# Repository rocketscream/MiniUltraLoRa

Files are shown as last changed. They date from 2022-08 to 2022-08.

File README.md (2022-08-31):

# Mini Ultra LoRa
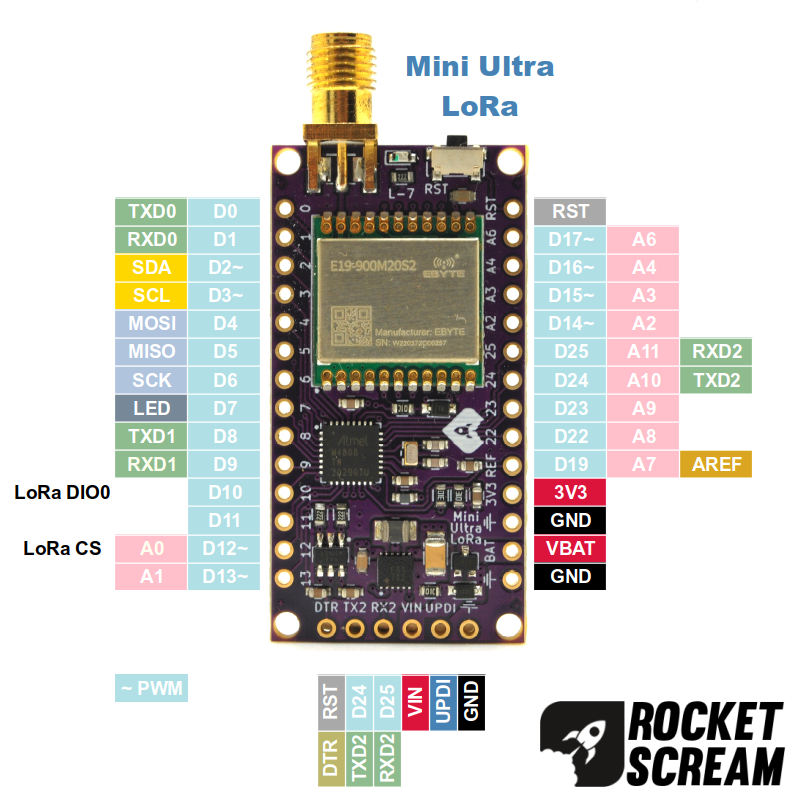
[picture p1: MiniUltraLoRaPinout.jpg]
Mini Ultra LoRa

Mini Ultra LoRa is an Arduino compatible ATmega4808 board that is suitable for ultra low power wireless applications. During deep sleep mode, the board consumes only 5 uA (with the on-board radio module in sleep mode) when powered by a 3.6 V source. The board comes equipped with a 2Kb I2C serial EEPROM with pre-programmed EUI-64™ MAC ID 24AA025E64T chip to be used as DEVEUI in a LoRaWAN network and E19-900M20S2 LoRa radio module. Option to use various battery type, cell combination and chemistry such as 2xAA or 3xAA (alkaline, NiMH), CR123A, LiFeFO4, and Li-Ion/Pol. No charger IC is included on-board.

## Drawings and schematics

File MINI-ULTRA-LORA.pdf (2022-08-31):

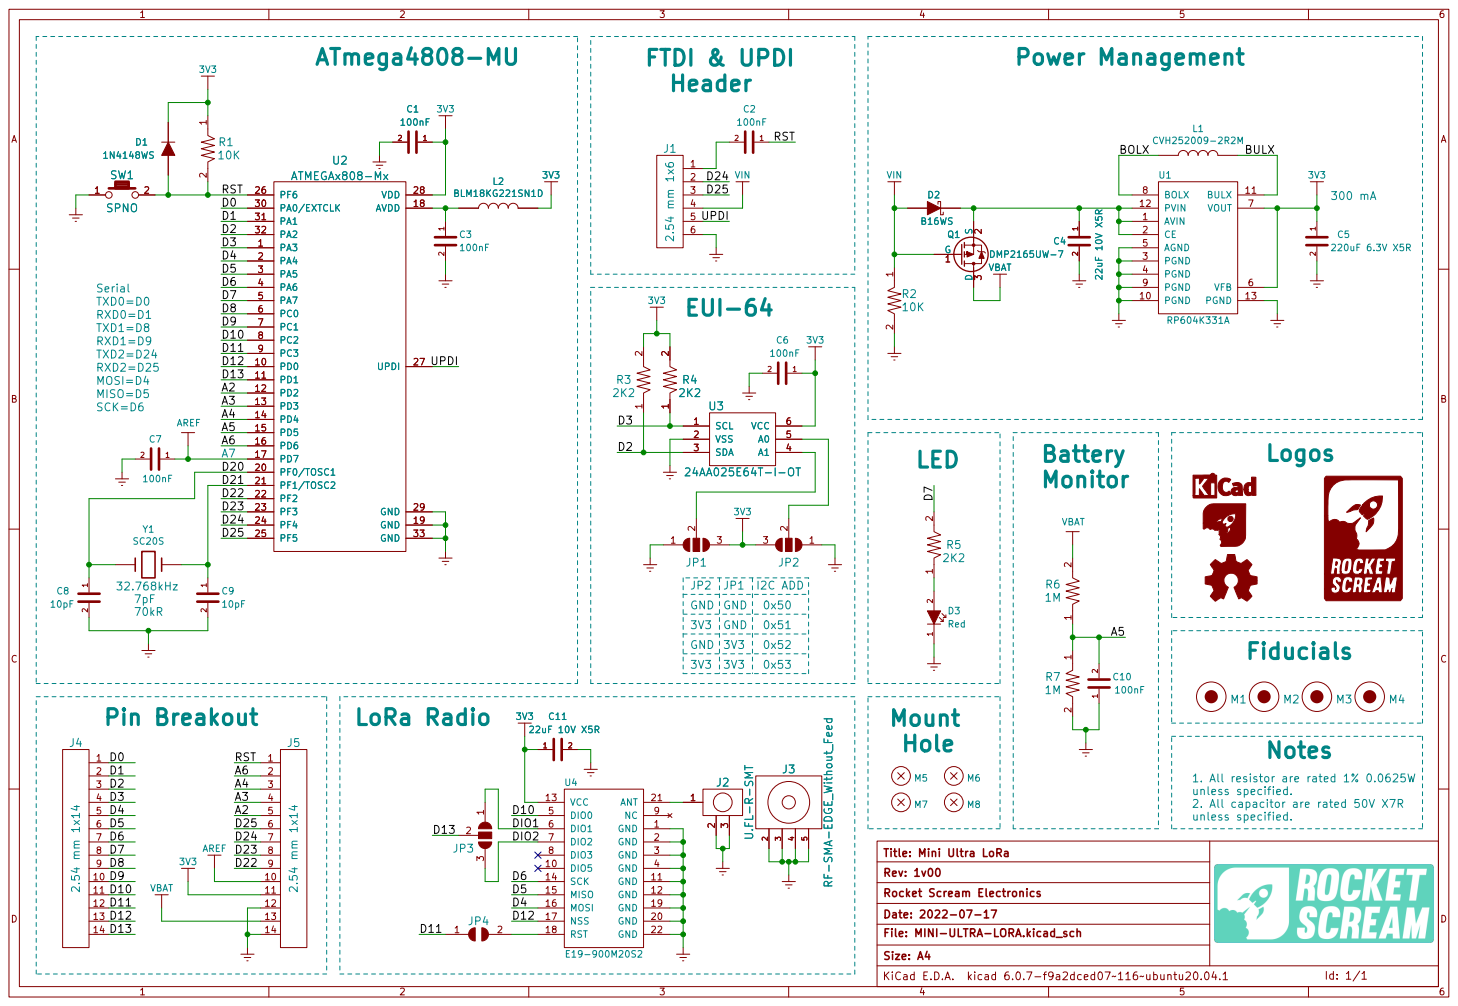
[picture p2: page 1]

JP2 | | I2C ADD
GND
3V3 | GND | 0x51

3 J2 GND U.FL-R-SMT 1 DIO5 10 GND 11 GND 12 VCC 13 SCK 14 MISO 15 MOSI 16 NSS 17 RST 18 GND 19 GND 2 GND 20 ANT 21 GND 22 GND 3 GND 4 DIO0 5 DIO1 6 DIO2 7 DIO3 8 NC 9 U4E19-900M20S2

1. All resistor are rated 1% 0.0625W unless specified.

2. All capacitor are rated 50V X7R
unless specified.

Id: 1/1 Title: Mini Ultra LoRa File: MINI-ULTRA-LORA.kicad_sch Rocket Scream Electronics
D Date: 2022-07-17 KiCad E.D.A. kicad 6.0.7-f9a2dced07~116~ubuntu20.04.1 Rev: 1v00 Size: A4

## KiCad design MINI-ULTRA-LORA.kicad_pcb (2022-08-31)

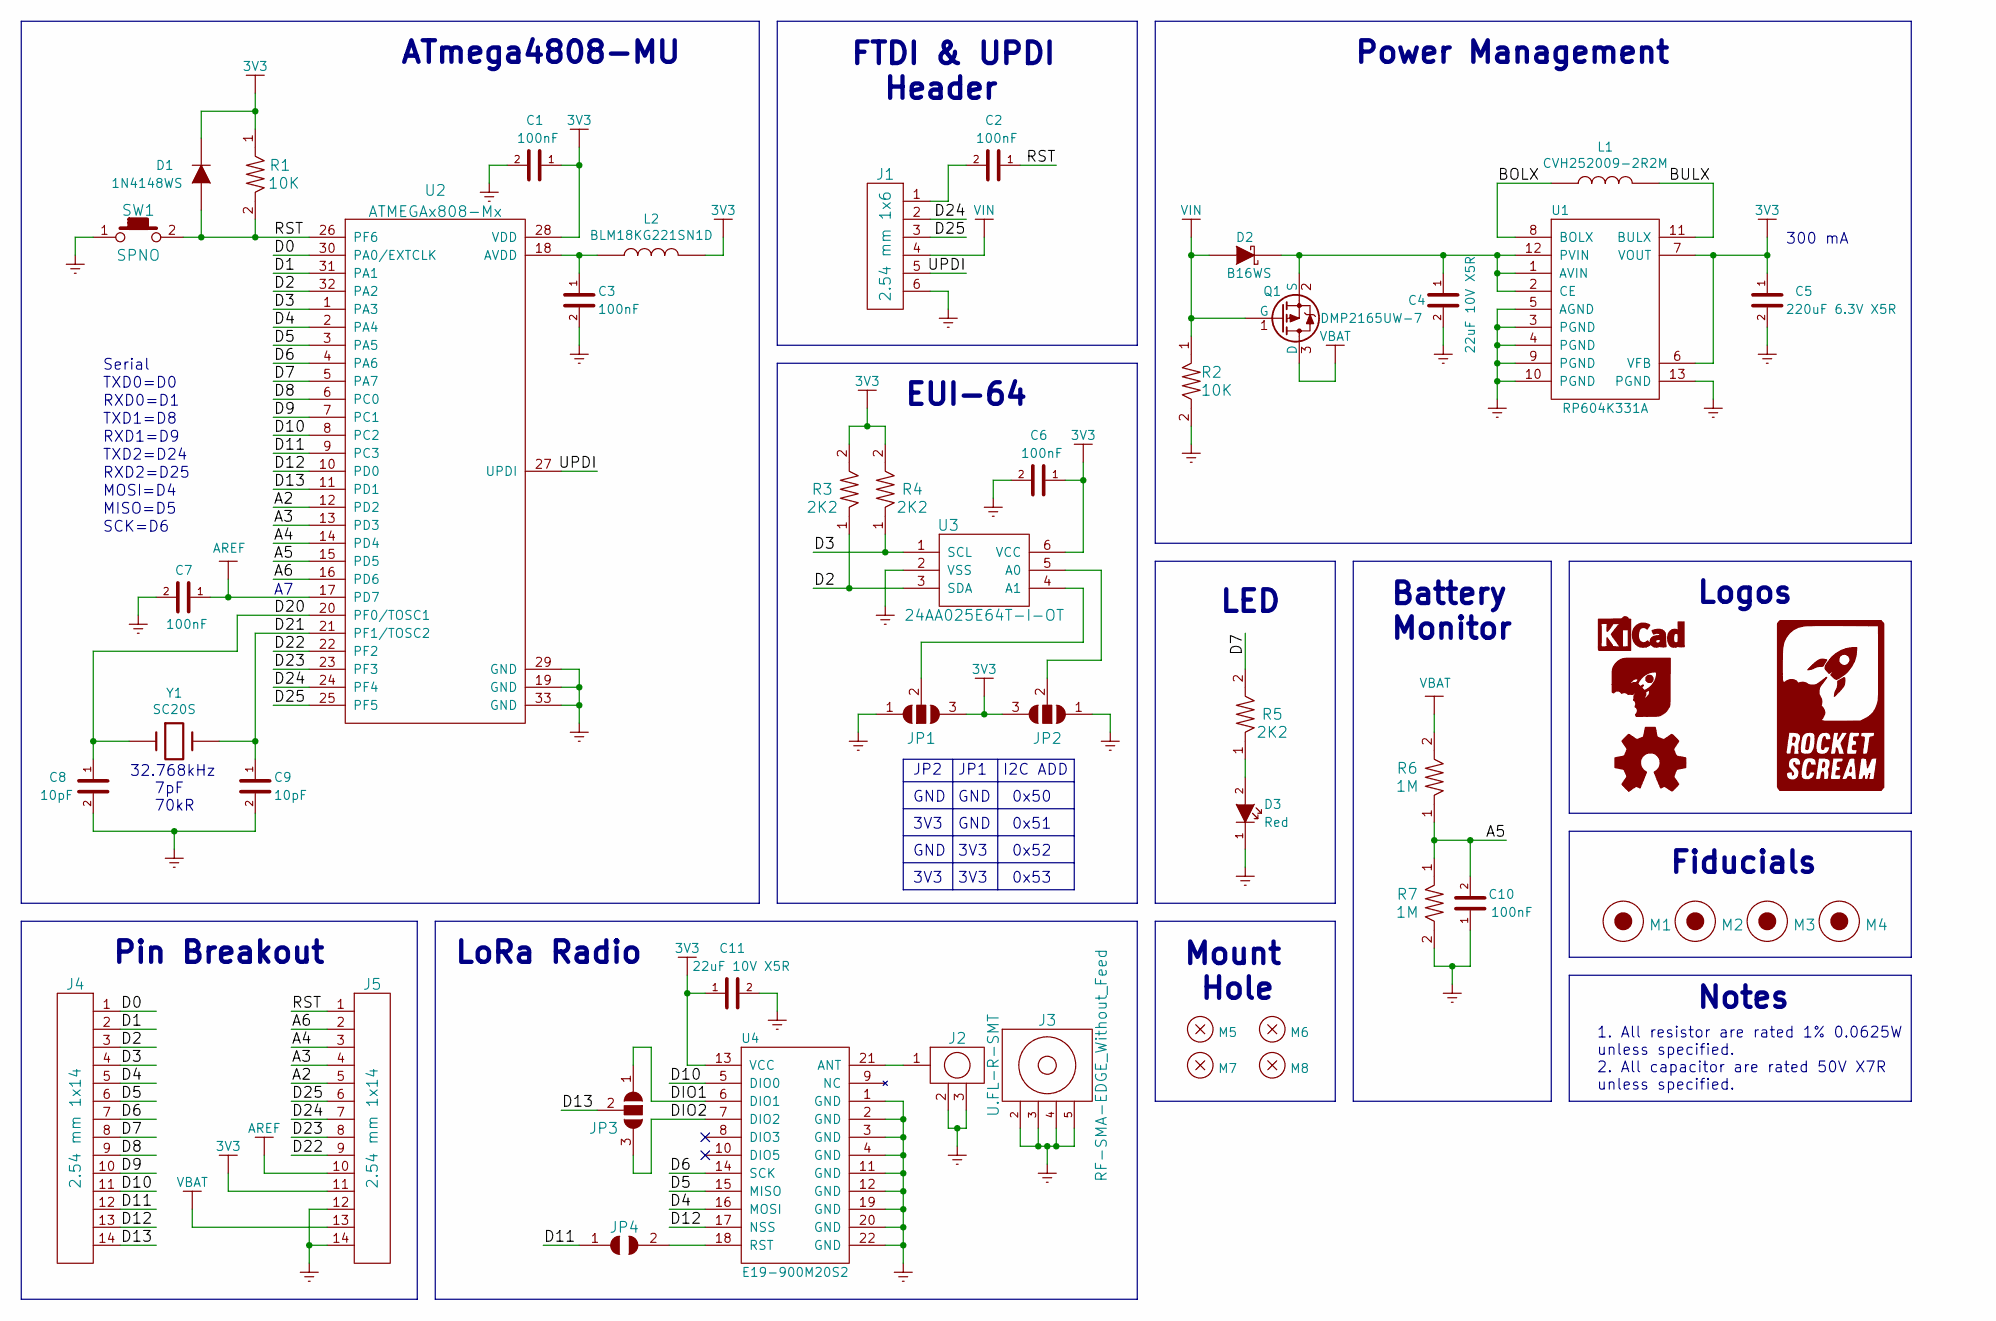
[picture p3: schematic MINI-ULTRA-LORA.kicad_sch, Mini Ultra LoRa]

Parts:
C1, C2, C3, C6, C7, C10: 100nF; C_0603
C4, C11: 22uF 10V X5R; C_0603
C5: 220uF 6.3V X5R; C_1206
C8, C9: 10pF; C_0603
D1: 1N4148WS; SOD-323
D2: B16WS; SOD-323
D3: Red; LED_0603
J1: 2.54 mm 1x6; HDR_1x6_Pitch2.54mm
J2: U.FL-R-SMT
J3: RF-SMA-EDGE_Without_Feed
J4, J5: 2.54 mm 1x14; HDR_1x14_Pitch2.54mm
JP1, JP2, JP3: JUMPER-2-WAY; JUMPER-2-WAY-SMD
JP4: JUMPER-1-WAY; JUMPER-1-WAY-SMD
L1: CVH252009-2R2M; I_2520
L2: BLM18KG221SN1D; I_0603
LOGO1: LOGO-KICAD; LOGO-KICAD_XXXSmall
LOGO2: LOGO-ROCKET-SCREAM-WITHOUT-TEXT; LOGO-ROCKET-SCREAM_Without_Text_XXXXSmall
LOGO3: LOGO-ROCKET-SCREAM-VERTICAL; LOGO-ROCKET-SCREAM_Vertical_XSmall
LOGO4: LOGO-OSHW; LOGO-OSHW_XXSmall
M1, M2, M3, M4: FIDUCIAL; FIDUCIAL-0.5MM_CROSS
M5, M6, M7, M8: MOUNT_HOLE; HOLE_NPTH_2.2MM
Q1: DMP2165UW-7; SOT-323
R1, R2: 10K; R_0603
R3, R4, R5: 2K2; R_0603
R6, R7: 1M; R_0603
SW1: SPNO; TS-1086E-12
U1: RP604K331A; DFN-12
U2: ATMEGAx808-Mx; QFN-32_5x5mm_Pitch0.5mm
U3: 24AA025E64T-I-OT; SOT-23-6
U4: E19-900M20S2
Y1: SC20S; SC-20S

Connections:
3V3: C1.1, C5.1, C6.1, C11.1, D1.1 (K), J5.11, JP1.3, JP2.3, L2.2, R1.1, R3.2, R4.2, U1.6 (VFB), U1.7 (VOUT), U2.28 (VDD), U3.6 (VCC), U4.13 (VCC)
/A2: J5.5, U2.12 (PD2)
/A3: J5.4, U2.13 (PD3)
/A4: J5.3, U2.14 (PD4)
/A5: C10.2, R6.1, R7.1, U2.15 (PD5)
/A6: J5.2, U2.16 (PD6)
/BOLX: L1.1, U1.8 (BOLX)
/BULX: L1.2, U1.11 (BULX)
/D0: J4.1, U2.30 (PA0/EXTCLK)
/D1: J4.2, U2.31 (PA1)
/D2: J4.3, R3.1, U2.32 (PA2), U3.3 (SDA)
/D3: J4.4, R4.1, U2.1 (PA3), U3.1 (SCL)
/D4: J4.5, U2.2 (PA4), U4.16 (MOSI)
/D5: J4.6, U2.3 (PA5), U4.15 (MISO)
/D6: J4.7, U2.4 (PA6), U4.14 (SCK)
/D7: J4.8, R5.2, U2.5 (PA7)
/D8: J4.9, U2.6 (PC0)
/D9: J4.10, U2.7 (PC1)
/D10: J4.11, U2.8 (PC2), U4.5 (DIO0)
/D11: J4.12, JP4.1, U2.9 (PC3)
/D12: J4.13, U2.10 (PD0), U4.17 (NSS)
/D13: J4.14, JP3.2, U2.11 (PD1)
/D20: C8.1, U2.20 (PF0/TOSC1), Y1.1
/D21: C9.1, U2.21 (PF1/TOSC2), Y1.2
/D22: J5.9, U2.22 (PF2)
/D23: J5.8, U2.23 (PF3)
/D24: J1.2, J5.7, U2.24 (PF4)
/D25: J1.3, J5.6, U2.25 (PF5)
/DIO1: JP3.1, U4.6 (DIO1)
/DIO2: JP3.3, U4.7 (DIO2)
/RST: C2.1, D1.2 (A), J5.1, R1.2, SW1.2, U2.26 (PF6)
/UPDI: J1.5, U2.27 (UPDI)
AREF: C7.1, J5.10, U2.17 (PD7)
GND: C1.2, C3.2, C4.2, C5.2, C6.2, C7.2, C8.2, C9.2, C10.1, C11.2, D3.1 (K), J1.6, J2.2, J2.3, J3.2, J3.3, J3.4, J3.5, J5.12, J5.14, JP1.1, JP2.1, R2.2, R7.2, SW1.1, U1.3 (PGND), U1.4 (PGND), U1.5 (AGND), U1.9 (PGND), U1.10 (PGND), U1.13 (PGND), U2.19 (GND), U2.29 (GND), U2.33 (GND), U3.2 (VSS), U4.1 (GND), U4.2 (GND), U4.3 (GND), U4.4 (GND), U4.11 (GND), U4.12 (GND), U4.19 (GND), U4.20 (GND), U4.22 (GND)
unnamed: C2.2, J1.1
unnamed: C3.1, L2.1, U2.18 (AVDD)
unnamed: C4.1, D2.1 (K), Q1.2 (S), U1.1 (AVIN), U1.2 (CE), U1.12 (PVIN)
unnamed: D3.2 (A), R5.1
unnamed: J2.1, U4.21 (ANT)
unnamed: JP1.2, U3.4 (A1)
unnamed: JP2.2, U3.5 (A0)
unnamed: JP4.2, U4.18 (RST)
VBAT: J5.13, Q1.3 (D), R6.2
VIN: D2.2 (A), J1.4, Q1.1 (G), R2.1

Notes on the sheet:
Notes
Logos
3V3
FTDI & UPDI Header
GND
0x52
Serial
TXD0=D0
MOSI=D4
300 mA
TXD2=D24
RXD0=D1
EUI-64
1. All resistor are rated 1% 0.0625W unless specified. 2. All capacitor are rated 50V X7R unless specified.
ATmega4808-MU
MISO=D5
Power Management
JP2
LED
Mount Hole
SCK=D6
Battery Monitor
Pin Breakout
RXD1=D9
32.768kHz 7pF 70kR
Fiducials
I2C ADD
RXD2=D25
LoRa Radio
0x53
0x51
0x50
JP1
TXD1=D8

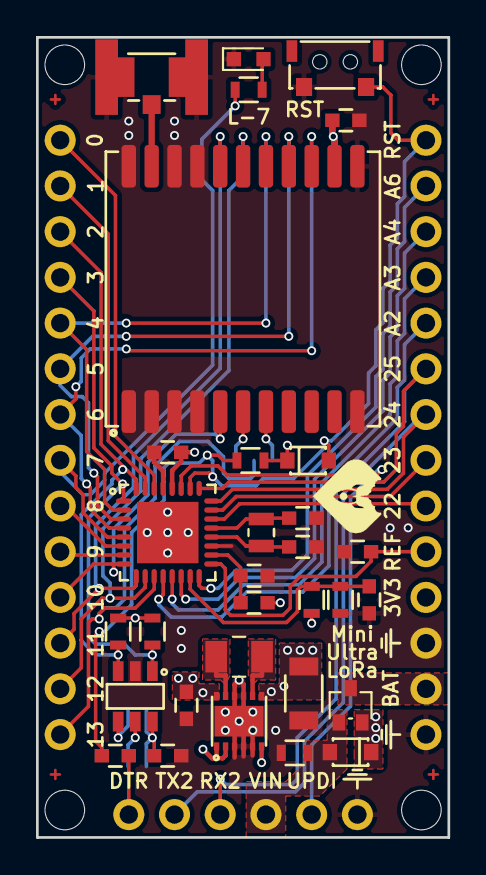
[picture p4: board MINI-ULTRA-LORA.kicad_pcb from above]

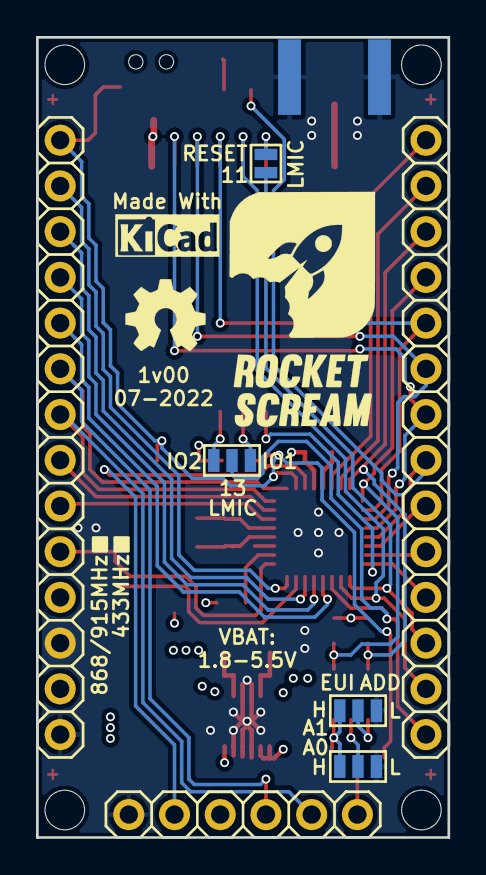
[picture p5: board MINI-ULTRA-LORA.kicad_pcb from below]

Board: 4 copper layers, 22.9 x 44.4 mm, 51 parts (10 on the bottom side), 44 nets.

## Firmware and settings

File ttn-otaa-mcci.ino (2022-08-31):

/*******************************************************************************
   Copyright (c) 2015 Thomas Telkamp and Matthijs Kooijman
   Copyright (c) 2018 Terry Moore, MCCI

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
   This example sends a valid LoRaWAN packet with payload "Hello,
   world!", using frequency and encryption settings matching those of
   the The Things Network.

   This uses OTAA (Over-the-air activation), where where a DevEUI and
   application key is configured, which are used in an over-the-air
   activation procedure where a DevAddr and session keys are
   assigned/generated for use with all further communication.

   Note: LoRaWAN per sub-band duty-cycle limitation is enforced (1% in
   g1, 0.1% in g2), but not the TTN fair usage policy (which is probably
   violated by this sketch when left running for longer)!

   To use this sketch, first register your application and device with
   the things network, to set or generate an AppEUI, DevEUI and AppKey.
   Multiple devices can use the same AppEUI, but each device has its own
   DevEUI and AppKey.

   Do not forget to define the radio type correctly in
   arduino-lmic/project_config/lmic_project_config.h or from your BOARDS.txt.

 *******************************************************************************/

#include <lmic.h>
#include <hal/hal.h>
#include <SPI.h>
#include <Wire.h>
#include <RocketScream_RTCAVRZero.h>
#include <RocketScream_LowPowerAVRZero.h>
#define EUI64_CHIP_ADDRESS 0x50
#define EUI64_MAC_ADDRESS 0xF8
#define EUI64_MAC_LENGTH 0x08
#define MAX_DATA_SIZE 2

const uint8_t unusedPins[] = {0, 1, 8, 9, 14, 15, 16, 17, 18, 22, 23, 24, 25};
//
// For normal use, we require that you edit the sketch to replace FILLMEIN
// with values assigned by the TTN console. However, for regression tests,
// we want to be able to compile these scripts. The regression tests define
// COMPILE_REGRESSION_TEST, and in that case we define FILLMEIN to a non-
// working but innocuous value.
//
#ifdef COMPILE_REGRESSION_TEST
# define FILLMEIN 0
#else
# warning "You must replace the values marked FILLMEIN with real values from the TTN control panel!"
# define FILLMEIN (#dont edit this, edit the lines that use FILLMEIN)
#endif

// This EUI must be in little-endian format, so least-significant-byte
// first. When copying an EUI from ttnctl output, this means to reverse
// the bytes. For TTN issued EUIs the last bytes should be 0xD5, 0xB3,
// 0x70.
static const u1_t PROGMEM APPEUI[8] = { 0x00, 0x00, 0x00, 0x00, 0x00, 0x00, 0x00, 0x00 };;
void os_getArtEui (u1_t* buf) {
  memcpy_P(buf, APPEUI, 8);
}

// This should also be in little endian format, see above.
u1_t DEVEUI[EUI64_MAC_LENGTH];
void os_getDevEui (u1_t* buf) {
  memcpy(buf, DEVEUI, 8);
}

// This key should be in big endian format (or, since it is not really a
// number but a block of memory, endianness does not really apply). In
// practice, a key taken from ttnctl can be copied as-is.
static const u1_t PROGMEM APPKEY[16] = { 0x00, 0x00, 0x00, 0x00, 0x00, 0x00, 0x00, 0x00, 0x00, 0x00, 0x00, 0x00, 0x00, 0x00, 0x00, 0x00 };
void os_getDevKey (u1_t* buf) {
  memcpy_P(buf, APPKEY, 16);
}

static uint8_t data[MAX_DATA_SIZE];
static osjob_t sendjob;

// Schedule TX every this many seconds (might become longer due to duty
// cycle limitations).
const unsigned TX_INTERVAL = 60;

// Pin mapping
const lmic_pinmap lmic_pins = {
  .nss = 12,
  .rxtx = LMIC_UNUSED_PIN,
  .rst = 11,
  .dio = {10, 13, LMIC_UNUSED_PIN},
};

void printHex2(unsigned v) {
  v &= 0xff;
  if (v < 16)
    Serial2.print('0');
  Serial2.print(v, HEX);
}

void onEvent (ev_t ev) {
  Serial2.print(os_getTime());
  Serial2.print(": ");
  switch (ev) {
    case EV_SCAN_TIMEOUT:
      Serial2.println(F("EV_SCAN_TIMEOUT"));
      break;
    case EV_BEACON_FOUND:
      Serial2.println(F("EV_BEACON_FOUND"));
      break;
    case EV_BEACON_MISSED:
      Serial2.println(F("EV_BEACON_MISSED"));
      break;
    case EV_BEACON_TRACKED:
      Serial2.println(F("EV_BEACON_TRACKED"));
      break;
    case EV_JOINING:
      Serial2.println(F("EV_JOINING"));
      break;
    case EV_JOINED:
      Serial2.println(F("EV_JOINED"));
      {
        u4_t netid = 0;
        devaddr_t devaddr = 0;
        u1_t nwkKey[16];
        u1_t artKey[16];
        LMIC_getSessionKeys(&netid, &devaddr, nwkKey, artKey);
        Serial2.print("netid: ");
        Serial2.println(netid, DEC);
        Serial2.print("devaddr: ");
        Serial2.println(devaddr, HEX);
        Serial2.print("AppSKey: ");
        for (size_t i = 0; i < sizeof(artKey); ++i) {
          if (i != 0)
            Serial2.print("-");
          printHex2(artKey[i]);
        }
        Serial2.println("");
        Serial2.print("NwkSKey: ");
        for (size_t i = 0; i < sizeof(nwkKey); ++i) {
          if (i != 0)
            Serial2.print("-");
          printHex2(nwkKey[i]);
        }
        Serial2.println();
      }
      // Disable link check validation (automatically enabled
      // during join, but because slow data rates change max TX
      // size, we don't use it in this example.
      LMIC_setLinkCheckMode(0);
      break;
    /*
      || This event is defined but not used in the code. No
      || point in wasting codespace on it.
      ||
      || case EV_RFU1:
      ||     Serial2.println(F("EV_RFU1"));
      ||     break;
    */
    case EV_JOIN_FAILED:
      Serial2.println(F("EV_JOIN_FAILED"));
      break;
    case EV_REJOIN_FAILED:
      Serial2.println(F("EV_REJOIN_FAILED"));
      break;
    case EV_TXCOMPLETE:
      Serial2.println(F("EV_TXCOMPLETE (includes waiting for RX windows)"));
      if (LMIC.txrxFlags & TXRX_ACK)
        Serial2.println(F("Received ack"));
      if (LMIC.dataLen) {
        Serial2.print(F("Received "));
        Serial2.print(LMIC.dataLen);
        Serial2.println(F(" bytes of payload"));
      }
      digitalWrite(LED_BUILTIN, LOW);
      Serial2.flush();
      /* Time in seconds, true: repeat, false: once */
      RTCAVRZero.enableAlarm(TX_INTERVAL, false);
      RTCAVRZero.attachInterrupt(awake);
      /* RTC works down to standby mode only. In power down, PIT is required */
      LowPower.standby();
      // Schedule next transmission to be immediately after this
      os_setTimedCallback(&sendjob, os_getTime() + sec2osticks(1), do_send);

      break;
    case EV_LOST_TSYNC:
      Serial2.println(F("EV_LOST_TSYNC"));
      break;
    case EV_RESET:
      Serial2.println(F("EV_RESET"));
      break;
    case EV_RXCOMPLETE:
      // data received in ping slot
      Serial2.println(F("EV_RXCOMPLETE"));
      break;
    case EV_LINK_DEAD:
      Serial2.println(F("EV_LINK_DEAD"));
      break;
    case EV_LINK_ALIVE:
      Serial2.println(F("EV_LINK_ALIVE"));
      break;
    /*
      || This event is defined but not used in the code. No
      || point in wasting codespace on it.
      ||
      || case EV_SCAN_FOUND:
      ||    Serial2.println(F("EV_SCAN_FOUND"));
      ||    break;
    */
    case EV_TXSTART:
      Serial2.println(F("EV_TXSTART"));
      break;
    case EV_TXCANCELED:
      Serial2.println(F("EV_TXCANCELED"));
      break;
    case EV_RXSTART:
      /* do not print anything -- it wrecks timing */
      break;
    case EV_JOIN_TXCOMPLETE:
      Serial2.println(F("EV_JOIN_TXCOMPLETE: no JoinAccept"));
      break;

    default:
      Serial2.print(F("Unknown event: "));
      Serial2.println((unsigned) ev);
      break;
  }
}

void do_send(osjob_t* j)
{
  unsigned char counter;
  float batteryVoltage;
  int adcReading;
  int voltage;
  
  // Check if there is not a current TX/RX job running
  if (LMIC.opmode & OP_TXRXPEND) {
    Serial2.println(F("OP_TXRXPEND, not sending"));
  } else {
	// Enable pin D17 (A5) used for battery voltage monitoring
    LowPower.enablePinISC(17);
    pinMode(17, INPUT);
    
    delay(100);
    adcReading = analogRead(A5);
    // Discard inaccurate 1st reading
    adcReading = 0;
    // Perform averaging
    for (counter = 10; counter > 0; counter--)
    {
      adcReading += analogRead(A5);
    }
    // Disable D17 (A5) digital input buffer to reduce power consumption
    LowPower.disablePinISC(17);

    adcReading = adcReading / 10;
    // Convert to volts
    batteryVoltage = adcReading * (6.6 / 1023.0);

    Serial2.print(F("Battery: "));
    Serial2.print(batteryVoltage);
    Serial2.println(F(" V"));

    // Pack float into int with 2 decimal point resolution
    voltage = batteryVoltage * 100;
    data[0] = voltage >> 8;
    data[1] = voltage;
    // Prepare upstream data transmission at the next possible time.
    LMIC_setTxData2(1, data, sizeof(data), 0);

    Serial2.println(F("Packet queued"));
  }
  // Next TX is scheduled after TX_COMPLETE event.
}

void setDevEui(unsigned char* buf)
{
  Wire.begin();
  Wire.beginTransmission(EUI64_CHIP_ADDRESS);
  Wire.write(EUI64_MAC_ADDRESS);
  Wire.endTransmission();
  Wire.requestFrom(EUI64_CHIP_ADDRESS, EUI64_MAC_LENGTH);

  // Format needs to be little endian (LSB...MSB)
  while (Wire.available())
  {
    *buf-- = Wire.read();
  }
}

void setup()
{
  uint8_t index;
  int count;

  /* Ensure unused pins are not floating */
  /* Pin D17 (A5) is being used but for code simplicity, we disable it first */
  /* in setup() before enabling it during operation */
  for (index = 0; index < sizeof(unusedPins); index++)
  {
    pinMode(unusedPins[index], OUTPUT);
    digitalWrite(unusedPins[index], LOW);
    LowPower.disablePinISC(unusedPins[index]);
  }
  
  Serial2.swap(1);
  Serial2.begin(115200);
  Serial2.println(F("Starting"));
  setDevEui(&DEVEUI[EUI64_MAC_LENGTH - 1]);

  Serial2.print(F("DEVEUI: "));

  for (count = EUI64_MAC_LENGTH; count > 0; count--)
  {
    printHex2(DEVEUI[count - 1]);
  }
  Serial2.println();

  /* false: internal 32.768 kHz ULP oscillator */
  RTCAVRZero.begin(true);

  // LMIC init
  os_init();
  // Reset the MAC state. Session and pending data transfers will be discarded.
  LMIC_reset();
  LMIC.dn2Dr = DR_SF9;        // TTN uses SF9 for its RX2 window.
  LMIC_setClockError(MAX_CLOCK_ERROR * 10 / 100);
  // Start job (sending automatically starts OTAA too)
  do_send(&sendjob);
}

void loop() {
  os_runloop_once();
}

void awake(void)
{
  digitalWrite(LED_BUILTIN, HIGH);
  RTCAVRZero.disableAlarm();
  RTCAVRZero.detachInterrupt();
}
